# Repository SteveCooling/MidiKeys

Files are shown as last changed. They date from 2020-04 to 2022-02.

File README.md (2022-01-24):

# MidiKeys

Dissecting an old broken organ I got the idea to turn it into a MIDI keyboard.

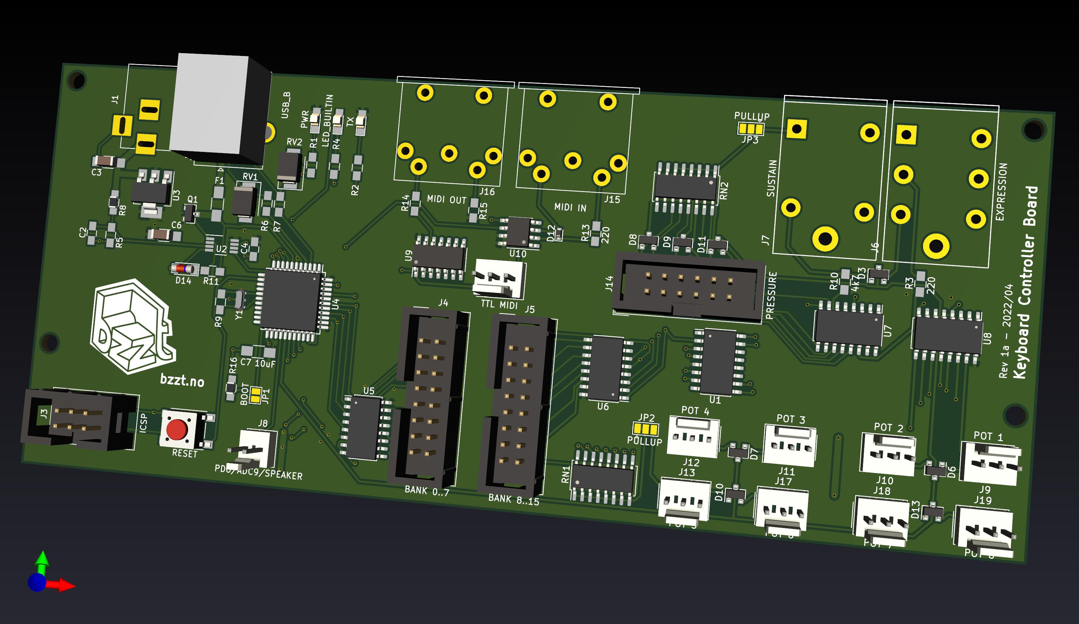
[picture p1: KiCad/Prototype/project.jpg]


I've since gotten a keybed that already had dual key switches for the velocity sensitivity, and been working on circuitry and code to support velocity sensitivity.

My plan is to produce a versatile open source keyboard controller board that can be used in various keyboard projects.

Works:

* Velocity sensitive multiplexed keyboard scanning
* Note off velocity sensitivity (not common in commercial keyboards, fun to be had here)

Plans:

* Work out the bugs in the keyboard scanner (keys sometimes hang or go undetected)
* Pot/slider (analog input) multiplexing
* Dedicated PCB with all required components and connectors
* Aftertouch support (channel pressure)
  * Maybe pseudo-polyphonic aftertouch is possible using a handful of pressure sensors (one per octave?) and interpolating the key pressure. Not sure about this.

Maybe in time:

* Mackie style DAW control support
* Keyboard splits and layers
* Interactive configuration from computer
* Arpeggiator with some cool touches?
  * Internal or MIDI timing
  * Oneshot/lick mode: Only arpeggiate when multiple keys are on, and in play order. Lay a chord and let the keyboard "slide" through the notes for you. In tempo.

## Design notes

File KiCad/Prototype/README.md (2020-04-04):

# Prototype keyboard controller

Based on Arduino Leonardo (ATMEGA32U4)

:warning: NOT FINISHED

Will be a complete board with decoders for multiplexed sampling of analog sources and up to 61-key keybeds

## Origins

This KiCad project is a derivative of the work found here: https://github.com/aspro648/Leonardo/

## Bill Of Materials

:warning: This list is from the original project, needs update when the board is ready
  
- 1 ea., Perfect Purple PCB from OSH Park, with not so perfect layout from kicad.pcb file.
- 1 ea., U1 IC REG LINEAR 3.3V 150MA SOT23-5, LP2985-33DBVRG4, https://www.digikey.com/short/j29pqr
- 1 ea., U2 IC OPAMP GP 1MHZ RRO 8VSSOP, LM358DGKR, https://www.digikey.com/short/jnd53r
- 1 ea., U3 IC REG LINEAR 5V 1A SOT223 NCP1117ST50T3G, https://www.digikey.com/short/j29pqc
- 1 ea., U4 ATMEGA32U4-AU, IC MCU 8BIT 32KB FLASH 44TQFP, https://www.digikey.com/short/jb25pc
- 1 ea., Q1 MOSFET P-CH 20V 2A SSOT3, FDN340P, https://www.digikey.com/short/j29ppj

- 1 ea., Y1 CER RES 16.0000MHZ 15PF SMD, CSTCE16M0V53-R0, https://www.digikey.com/short/j2b9cm
- 2 ea., C1, C5 CAP CER 1UF SMD 0805
- 1 ea., C2 CAP CER 22pF SMD 0805
- 2 ea., C3, C6, C7 CAP CER 10UF 25V 1206, https://www.digikey.com/short/j29pwm
- 1 ea., C4 CAP CER 0.1UF SMD 0805

- 4 ea., D1-D4 SMD LED 0805, https://www.digikey.com/short/jwj4rb
- 1 ea., F1 PTC 1206, Bel 0ZCJ0025AF2E, https://www.digikey.com/short/jfcbc8
- 2 ea., RV1, RV2 VARISTOR 	VARISTOR 10.8V 40A 0805, https://www.digikey.com/short/jwj45d
- 4 ea., R1-R4 Resistor 1K OHM SMD 0805, https://www.digikey.com/short/j2d0wt
- 2 ea., R5, R8 Resistor 10K OHM SMD 0805, https://www.digikey.com/short/j2d0w4
- 2 ea., R6, R7 Resistor 22 OHM SMD 0805, https://www.digikey.com/short/jwj45j
- 1 ea., R9 Resistor 1M OHM SMD 0603, 

- 1 ea., SW1 (yellow) SWITCH TACTILE SPST-NO 0.05A 12V, SW416-ND, https://www.digikey.com/short/jwj4m9
- or (purple) KSEM31J LFS https://www.digikey.com/short/jnqh3m
- 1 ea., X3, CONN RCPT MICRO USB R/A SMD, Molex 1050170001, https://www.digikey.com/short/jb2205
- 1 ea., J1 Barrel Jack, https://www.digikey.com/short/j2fz43
- 1 ea., 6-Pin header, https://www.digikey.com/short/jwj4w4
- 2 ea., 8-Pin header, https://www.digikey.com/short/jwj4dp
- 1 ea., 10-Pin header, https://www.digikey.com/short/jwj4n7
- 1 ea., 2x3 Pin header, http://www.digikey.com/short/3m33n0

## License

[Attribution-ShareAlike 3.0 United States (CC BY-SA 3.0 US)](https://creativecommons.org/licenses/by-sa/3.0/us/)

You are free to:

- Share — copy and redistribute the material in any medium or format
- Adapt — remix, transform, and build upon the material

Under the following terms:

- Attribution — You must give appropriate credit, provide a link to the license, and indicate if changes were made. You may do so in any reasonable manner, but not in any way that suggests the licensor endorses you or your use.
- ShareAlike — If you remix, transform, or build upon the material, you must distribute your contributions under the same license as the original.

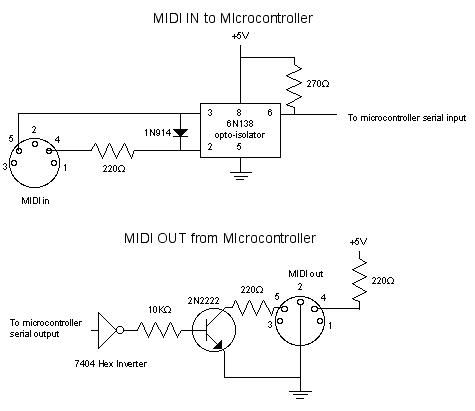
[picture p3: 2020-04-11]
KiCad/Prototype/documents/midi in out.jpg

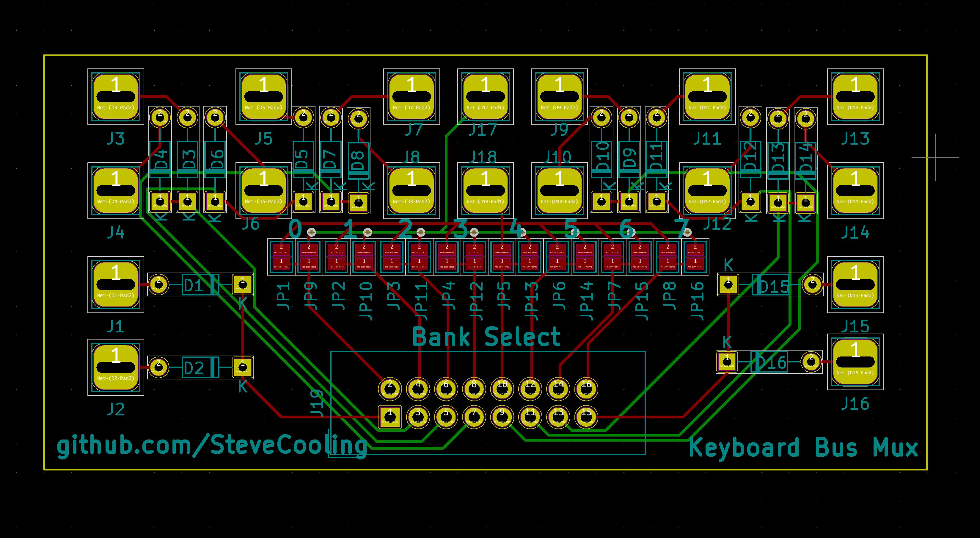
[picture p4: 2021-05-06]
KiCad/National Keyboard Mux Board/pcb0325.jpg

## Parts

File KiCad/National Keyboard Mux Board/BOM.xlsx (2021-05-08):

Comment | Designator | Footprint | LCSC Part #
Dual Common Cathode Diode | D8,D7,D6,D5,D4,D3,D2,D1 | SOT-23 | C82481

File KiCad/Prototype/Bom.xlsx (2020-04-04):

Description | Manufacturer Part Number | Manufacturer | Digi-Key Part Number | Customer Reference | Quantity | $ at Qty 1 | $ at Qty 25 | Total @ Qty 1 | Tota @ Qty 25
PCB |  | OSH Park | - | - | 1 | $9.48 | $5.72 | $9.48 | $5.72 | ~$2.60 JLCPCB?
IC REG LINEAR 3.3V 150MA SOT23-5 | LP2985-33DBVRG4 | Texas Instruments | 296-49790-1-ND | Leo U1 | 1 | $0.60 | $0.53 | $0.60 | $0.53
IC OPAMP GP 1MHZ RRO 8VSSOP | LMV358IDGKR | Texas Instruments | 296-13455-1-ND | Leo U2 | 1 | $0.80 | $0.71 | $0.80 | $0.71
IC MCU 8BIT 32KB FLASH 44TQFP | ATMEGA32U4-AUR | Microchip Technology | ATMEGA32U4-AURCT-ND | Leo U4 | 1 | $4.20 | $3.85 | $4.20 | $3.85
IC REG LINEAR 5V 1A SOT223 | NCP1117ST50T3G | ON Semiconductor | NCP1117ST50T3GOSCT-ND | Leo U3 | 1 | $0.54 | $0.46 | $0.54 | $0.46
MOSFET P-CH 20V 2A SSOT3 | FDN340P | ON Semiconductor | FDN340PCT-ND | Leo Q1 | 1 | $0.55 | $0.43 | $0.55 | $0.43
CER RES 16.0000MHZ 15PF SMD | CSTCE16M0V53-R0 | Murata Electronics North America | 490-1198-1-ND | Leo Y1 | 1 | $0.50 | $0.42 | $0.50 | $0.42
CAP CER 10UF 35V X5R 1206 | GRM319R6YA106KA12D | Murata Electronics North America | 490-9964-1-ND | Leo C3, C6, C7 | 3 | $0.41 | $0.16 | $1.23 | $0.48
CAP CER 0.1UF 25V X7R 0805 | CC0805KRX7R8BB104 | Yageo | 311-1141-1-ND | Leo C4 | 1 | $0.13 | $0.10 | $0.13 | $0.10
CAP CER 22PF 25V C0G/NP0 0805 | 885012007030 | Wurth Electronics Inc. | 732-7829-1-ND | Leo C2 | 1 | $0.10 | $0.05 | $0.10 | $0.05
CAP CER 1UF 25V X5R 0805 | CL21A105KAFNNNE | Samsung Electro-Mechanics | 1276-2887-1-ND | Leo C1, C5 | 2 | $0.19 | $0.14 | $0.38 | $0.28
PTC RESET FUSE 24V 250MA 1206 | 0ZCJ0025AF2E | Bel Fuse Inc. | 507-1799-1-ND | Leo F1 | 1 | $0.13 | $0.13 | $0.13 | $0.13
VARISTOR 10.8V 40A 0805 | VCUG080050L1DP | AVX Corporation | 478-5584-1-ND | Leo RV1, RV2 | 2 | $0.49 | $0.36 | $0.98 | $0.72
RES SMD 1K OHM 5% 1/8W 0805 | ERJ-6GEYJ102V | Panasonic Electronic Components | P1.0KACT-ND | Leo R1 - R4 | 4 | $0.10 | $0.03 | $0.40 | $0.12
RES SMD 10K OHM 5% 1/8W 0805 | ERJ-6GEYJ103V | Panasonic Electronic Components | P10KACT-ND | Leo R5, R8 | 2 | $0.10 | $0.03 | $0.20 | $0.06
RES SMD 22 OHM 5% 0.4W 0805 | ESR10EZPJ220 | Rohm Semiconductor | RHM22KCT-ND | Leo R6, R7 | 2 | $0.10 | $0.03 | $0.20 | $0.06
CRGCQ 0603 1M0 5% | CRGCQ0603J1M0 | TE Connectivity Passive Product | A130109CT-ND | Leo R9 | 1 | $0.10 | $0.03 | $0.10 | $0.03
LED ORANGE CLEAR SMD | LTST-C170KFKT | Lite-On Inc. | 160-1413-1-ND | Leo D1-D4 | 4 | $0.31 | $0.12 | $1.24 | $0.48
SWITCH TACTILE SPST-NO 0.05A 24V | B3S-1002 | Omron Electronics Inc-EMC Div | SW416-ND | Leo SW1 | 1 | $0.66 | $0.62 | $0.66 | $0.62
CONN RCPT MICRO USB R/A SMD | 1050170001 | Molex, LLC | WM1399CT-ND | Leo X3 | 1 | $0.87 | $0.72 | $0.87 | $0.72
CONN PWR JACK 2X5.5MM SOLDER | PJ-002A | CUI Inc. | CP-002A-ND | Leo J1 | 1 | $0.61 | $0.52 | $0.61 | $0.52
CONN HEADER FEMALE 6POS .1" TIN | PPTC061LFBN-RC | Sullins Connector Solutions | S7004-ND | Leo | 1 | $0.52 | $0.48 | $0.52 | $0.48
CONN HEADER FEMALE 8POS .1" TIN | PPTC081LFBN-RC | Sullins Connector Solutions | S7006-ND | Leo | 2 | $0.65 | $0.61 | $1.30 | $1.22
CONN HEADER FEMALE 10POS.1" TIN | PPTC101LFBN-RC | Sullins Connector Solutions | S7008-ND | Leo | 1 | $0.65 | $0.57 | $0.65 | $0.57
 |  |  |  |  |  |  |  | $26.37 | $18.76

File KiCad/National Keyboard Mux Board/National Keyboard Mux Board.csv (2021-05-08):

Id | Designator | Footprint | Quantity | Designation | LCSC
1 | D8,D7,D6,D5,D4,D3,D2,D1 | SOT-23 | 8 | BAV74LT1G | C82481

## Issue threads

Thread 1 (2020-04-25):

Key changes are sometimes not detected

SteveCooling, 2020-04-25:
Sometimes a note will hang (not turn off) or not get detected.

This might be caused by bounce in the switches combined with the fact that we send a XOR of the state out of the keyboard reader.

Try to:
* Stop using XOR to get a definitive state of each key.
* Internalize the velocity logic into KeyboardMux - direct access to the key states and easier to work with for the user.

SteveCooling, 2020-05-05:
It seems this issue was a race condition in MidiKeys::loop() where PORTB would change over time when it was assumed to be the same. Earlier timing optimizations obviously made this better.

I'm now making a copy of the data on PORTB and using it for the duration of the function call, and I think that solved the issue. Needs more testing though. 🎶

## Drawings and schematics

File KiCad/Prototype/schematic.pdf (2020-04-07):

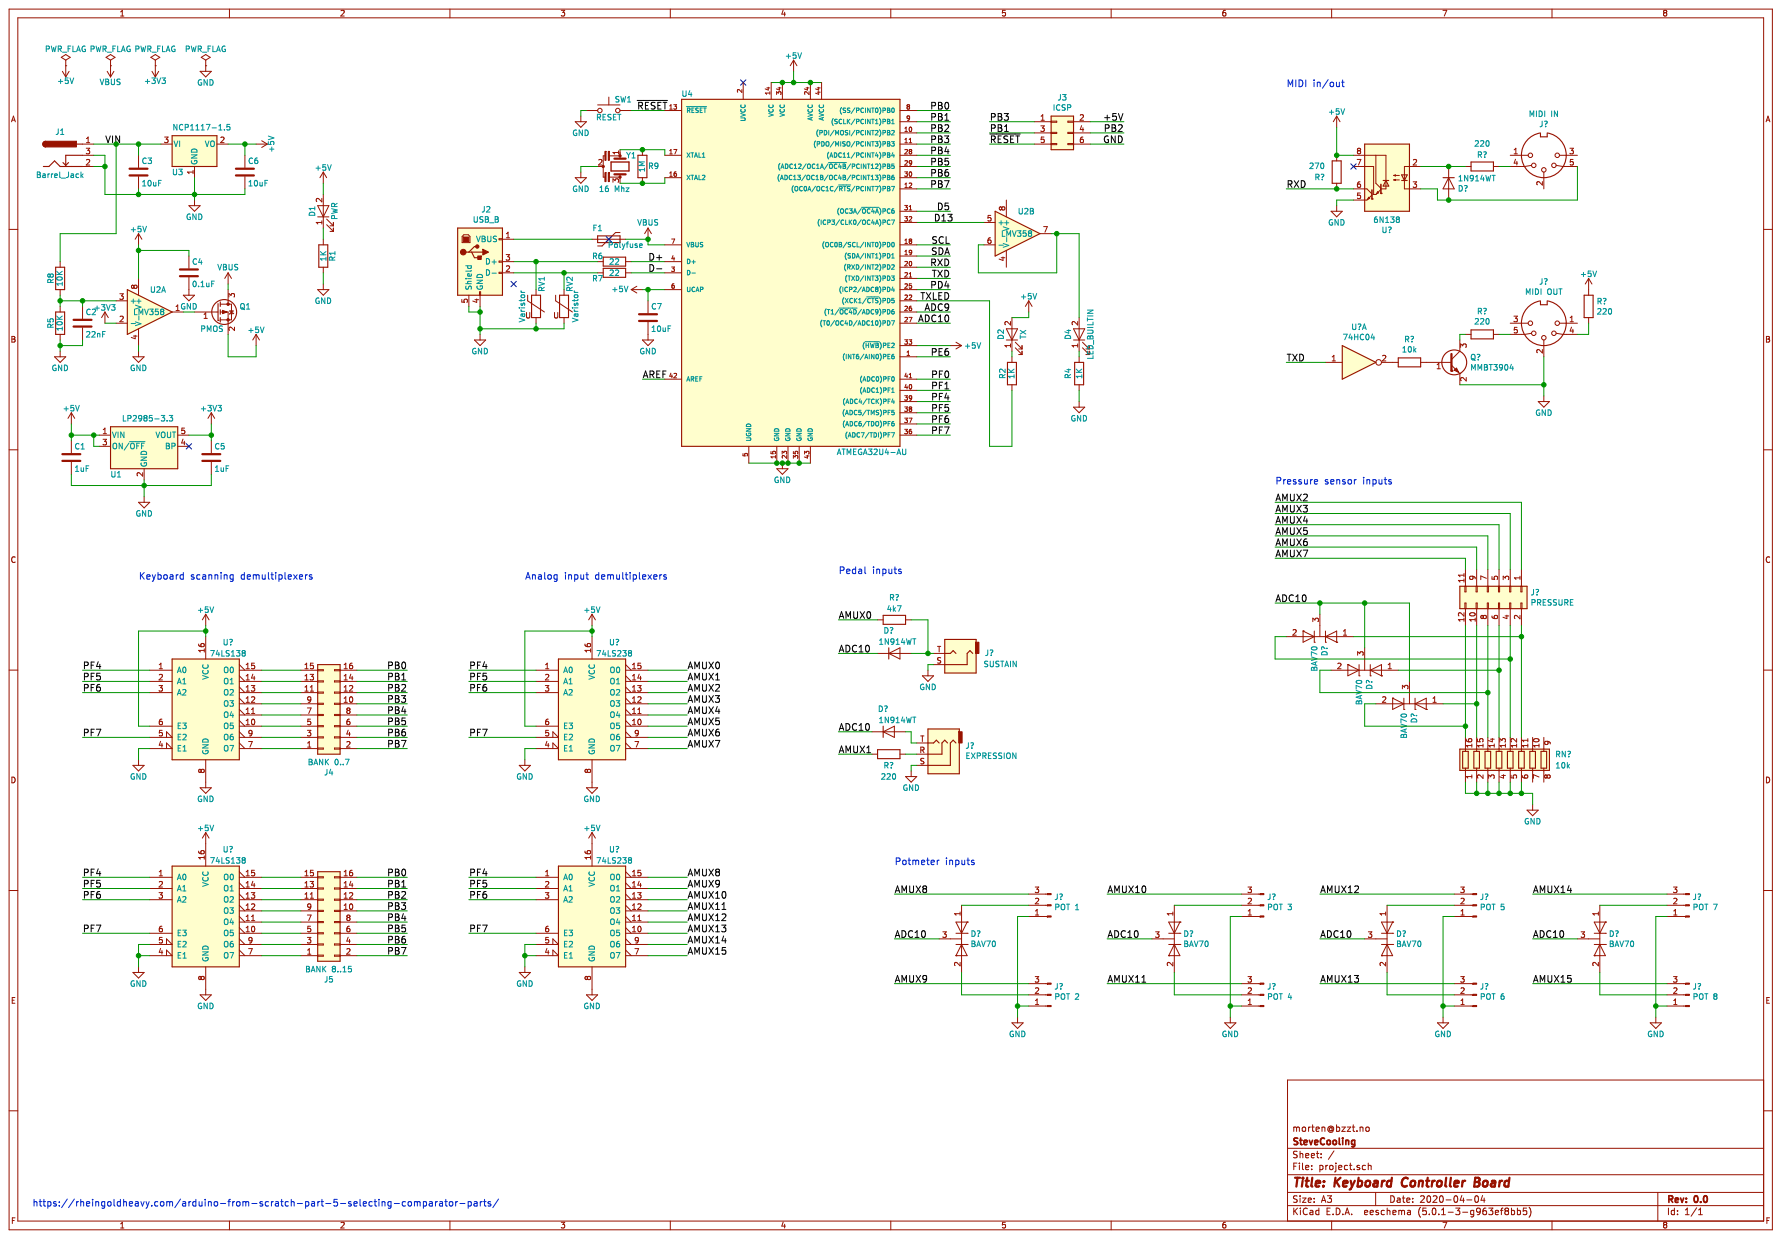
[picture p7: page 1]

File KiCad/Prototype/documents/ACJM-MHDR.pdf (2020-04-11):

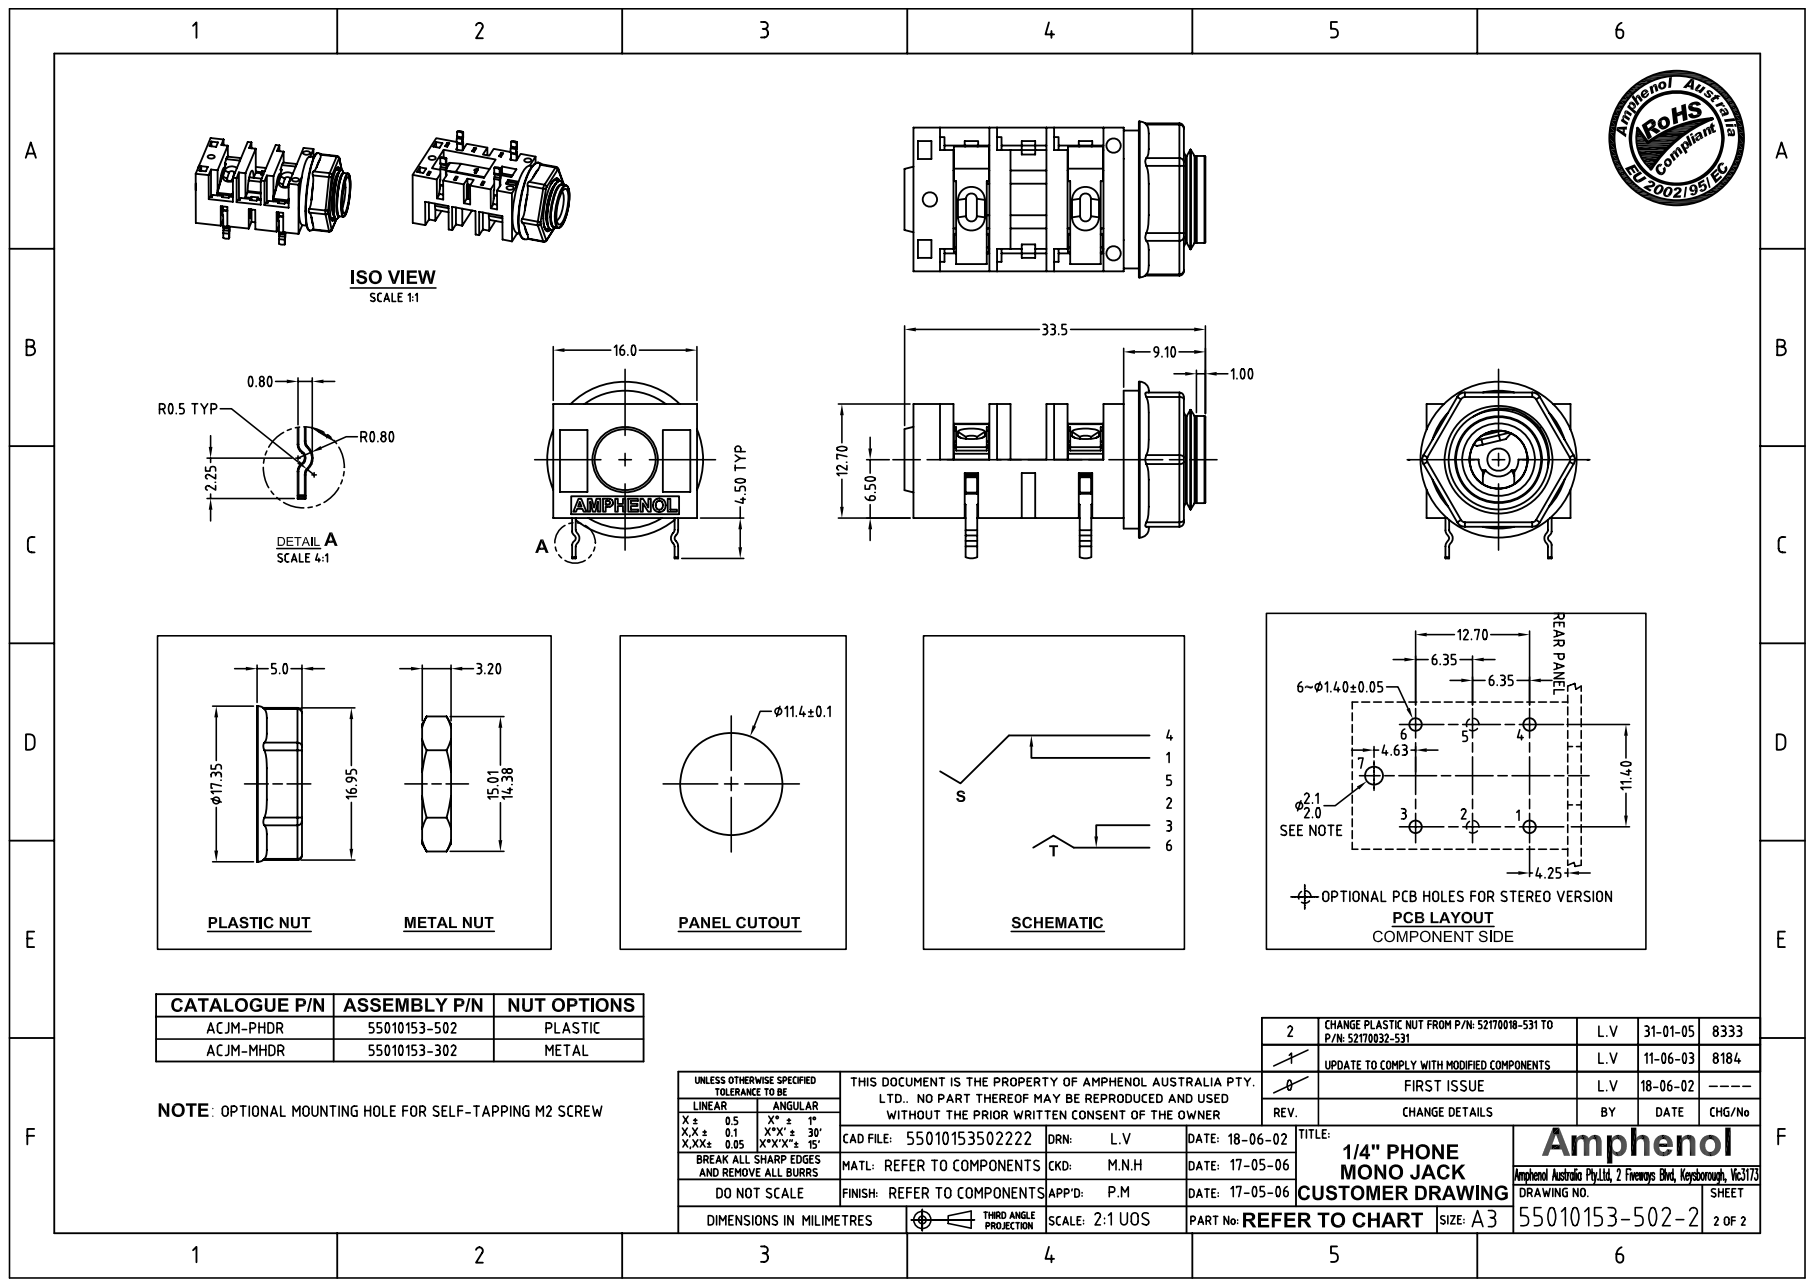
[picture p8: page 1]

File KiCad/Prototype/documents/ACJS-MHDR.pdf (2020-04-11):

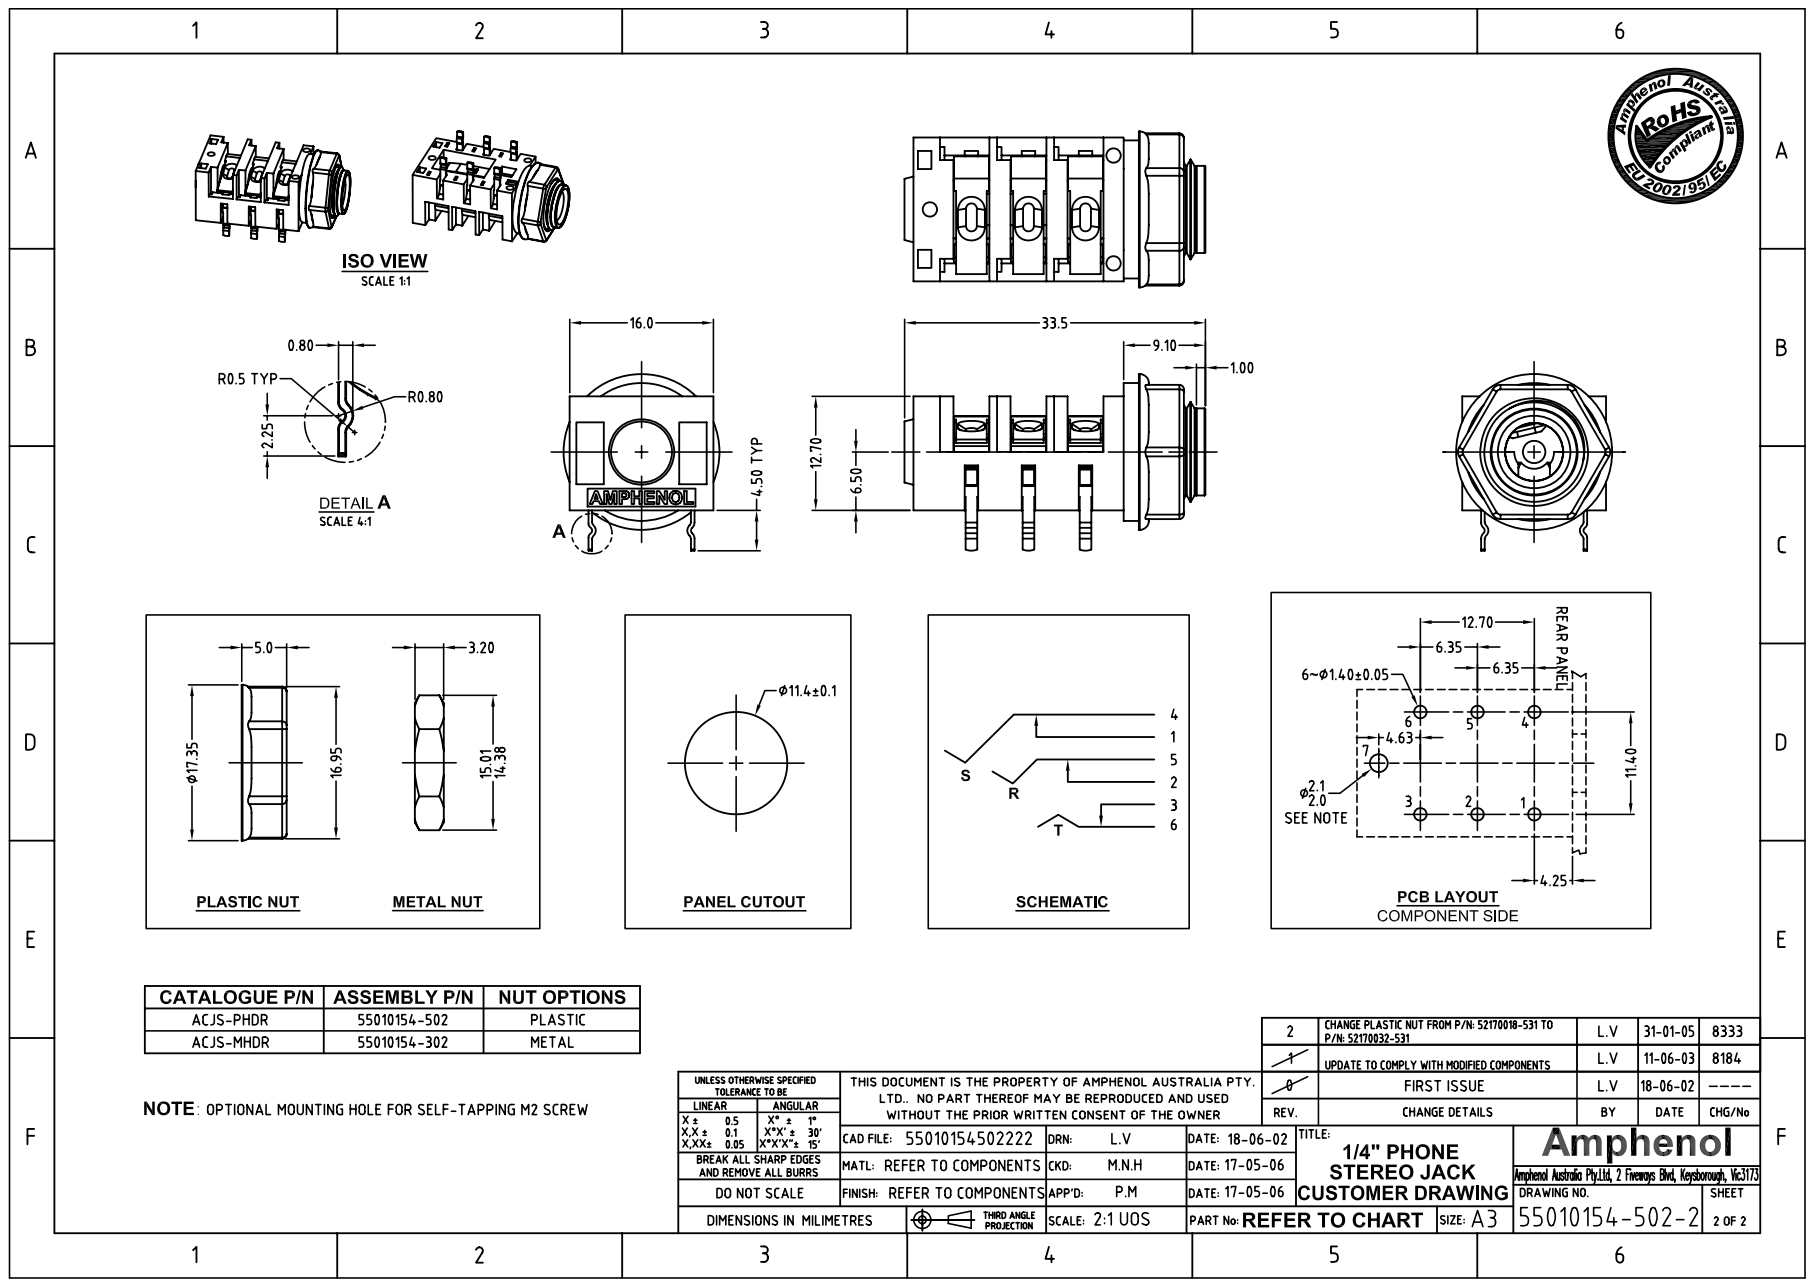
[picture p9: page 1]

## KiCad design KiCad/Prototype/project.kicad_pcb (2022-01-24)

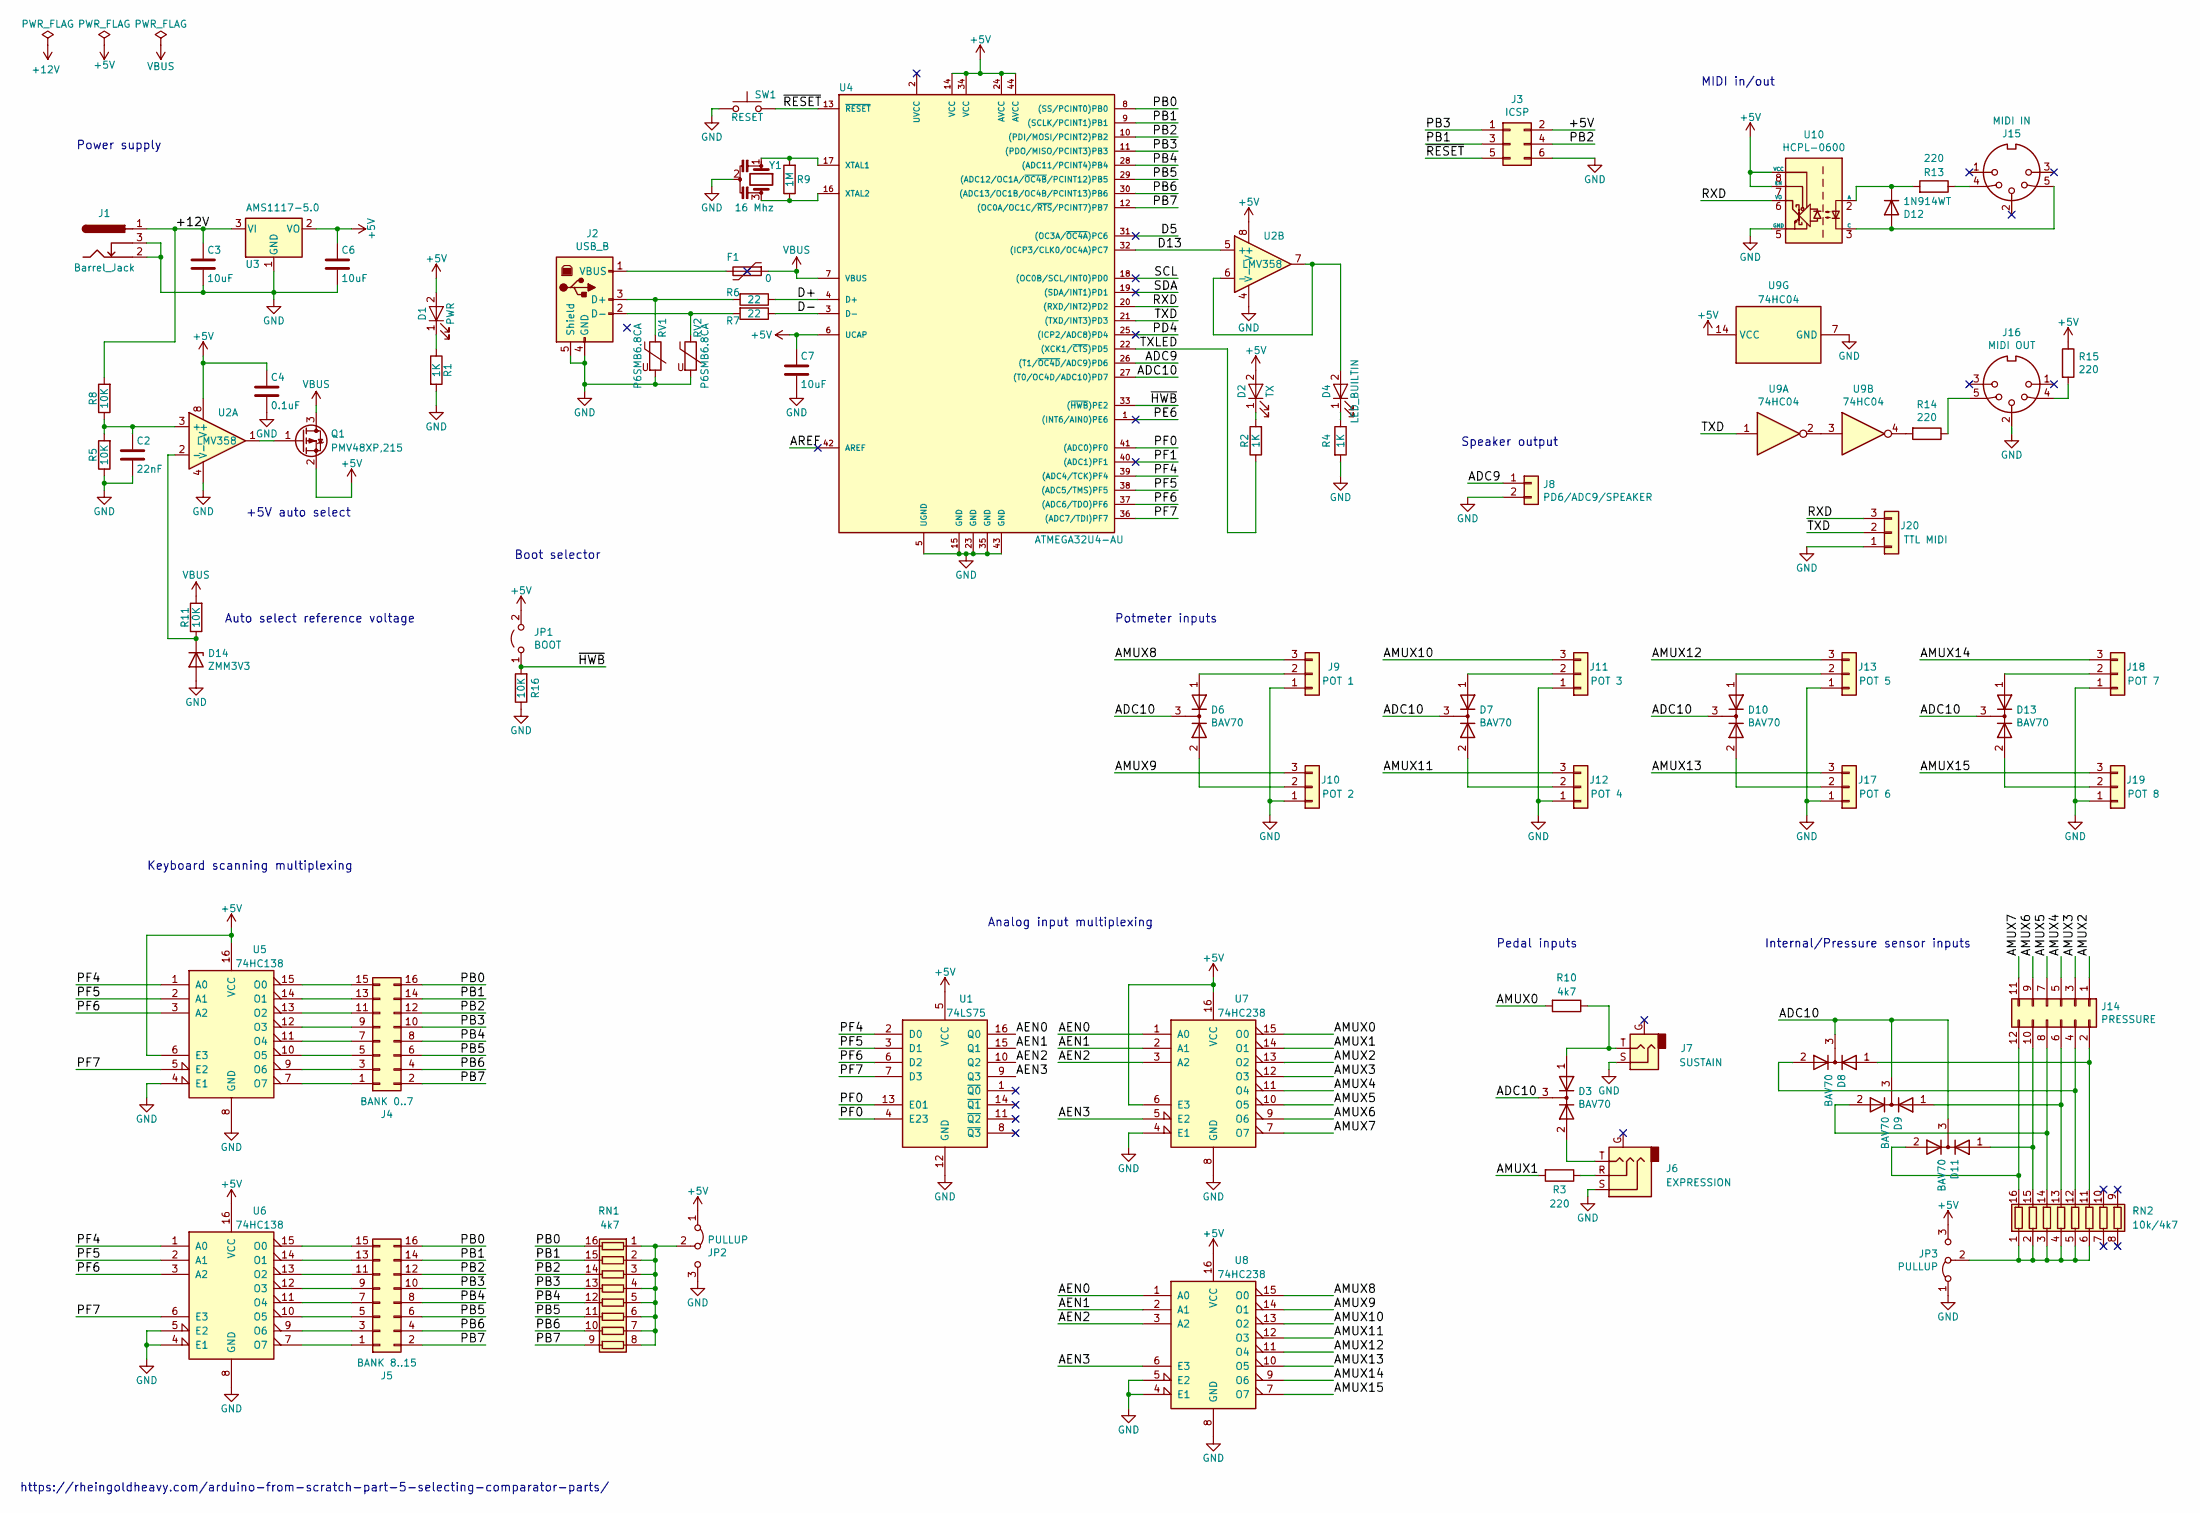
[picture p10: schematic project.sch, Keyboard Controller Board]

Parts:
C2: 22nF; C_0805_HandSoldering; LCSC C1729
C3, C6, C7: 10uF; C_1206_HandSoldering; LCSC C13585
C4: 0.1uF; C_0805_HandSoldering; LCSC C49678
D1: PWR; LED_0805_HandSoldering; LCSC C84256
D2: TX; LED_0805_HandSoldering; LCSC C84256
D3, D6, D7, D8, D9, D10, D11, D13: BAV70; SOT-23; LCSC C68978
D4: LED_BUILTIN; LED_0805_HandSoldering; LCSC C84256
D12: 1N914WT; D_SOD-323; LCSC C2128
D14: ZMM3V3; D_MiniMELF; LCSC C8056
F1: 0; R_1206_HandSoldering; LCSC C17888
J1: Barrel_Jack; BARREL_JACK; MOUSER 490-PJ-102A
J2: USB_B; USB_B_OST_USB-B1HSxx_Horizontal; MOUSER 490-UJ2-BH-1-TH
J3: ICSP; IDC-Header_2x03_P2.54mm_Vertical; MOUSER 517-30306-6002HB
J4: BANK 0..7; IDC-Header_2x08_P2.54mm_Vertical; MOUSER 517-30316-6002
J5: BANK 8..15; IDC-Header_2x08_P2.54mm_Vertical; MOUSER 517-30316-6002
J6: EXPRESSION; Jack_6.35mm_Amphenol_ACJS-MHDR; MOUSER 523-ACJS-MHOP
J7: SUSTAIN; Jack_6.35mm_Amphenol_ACJM-MHDR; MOUSER 523-ACJS-MHOP
J8: PD6/ADC9/SPEAKER; Molex_KK-254_AE-6410-02A_1x02_P2.54mm_Vertical; MOUSER 571-640454-2
J9: POT 1; Molex_KK-254_AE-6410-03A_1x03_P2.54mm_Vertical; MOUSER 571-6404543
J10: POT 2; Molex_KK-254_AE-6410-03A_1x03_P2.54mm_Vertical; MOUSER 571-6404543
J11: POT 3; Molex_KK-254_AE-6410-03A_1x03_P2.54mm_Vertical; MOUSER 571-6404543
J12: POT 4; Molex_KK-254_AE-6410-03A_1x03_P2.54mm_Vertical; MOUSER 571-6404543
J13: POT 5; Molex_KK-254_AE-6410-03A_1x03_P2.54mm_Vertical; MOUSER 571-6404543
J14: PRESSURE; IDC-Header_2x06_P2.54mm_Vertical
J15: MIDI IN; DIN_5_180Deg_PSG03463; MOUSER 806-KCDX-5S-N2
J16: MIDI OUT; DIN_5_180Deg_PSG03463; MOUSER 806-KCDX-5S-N2
J17: POT 6; Molex_KK-254_AE-6410-03A_1x03_P2.54mm_Vertical; MOUSER 571-6404543
J18: POT 7; Molex_KK-254_AE-6410-03A_1x03_P2.54mm_Vertical; MOUSER 571-6404543
J19: POT 8; Molex_KK-254_AE-6410-03A_1x03_P2.54mm_Vertical; MOUSER 571-6404543
J20: TTL MIDI; Molex_KK-254_AE-6410-03A_1x03_P2.54mm_Vertical; MOUSER 571-6404543
JP1: BOOT; SolderJumper-2_P1.3mm_Open_Pad1.0x1.5mm
JP2, JP3: PULLUP; SolderJumper-3_P1.3mm_Bridged12_Pad1.0x1.5mm
Q1: PMV48XP,215; SOT-23; LCSC C75560
R1, R2, R4: 1K; R_0805_HandSoldering; LCSC C17513
R3, R13, R14, R15: 220; C_0805_HandSoldering; LCSC C17557
R5, R8, R11, R16: 10K; R_0805_HandSoldering; LCSC C17414
R6, R7: 22; R_0805_HandSoldering; LCSC C17561
R9: 1M; R_0805_HandSoldering; LCSC C17514
R10: 4k7; C_0805_HandSoldering; LCSC C17673
RN1: 4k7; SOIC-16_4.55x10.3mm_P1.27mm
RN2: 10k/4k7; SOIC-16_4.55x10.3mm_P1.27mm
RV1, RV2: P6SMB6.8CA; D_SMB; LCSC C78395
SW1: RESET; SW_SPST_PTS645
U1: 74LS75; SOIC-16_4.55x10.3mm_P1.27mm
U2: LMV358; VSSOP-8_3.0x3.0mm_Pitch0.65mm
U3: AMS1117-5.0; SOT-223-3_TabPin2; LCSC C6187
U4: ATMEGA32U4-AU; TQFP-44_10x10mm_Pitch0.8mm; MOUSER 556-ATMEGA32U4-AU
U5, U6: 74HC138; SOIC-16_4.55x10.3mm_P1.27mm; MOUSER 771-74HC138D
U7, U8: 74HC238; SOIC-16_4.55x10.3mm_P1.27mm; MOUSER 771-74HC238D
U9: 74HC04; SOIC-14_3.9x8.7mm_P1.27mm
U10: HCPL-0600; SOIC-8_3.9x4.9mm_P1.27mm; MOUSER 512-HCPL0600
Y1: 16 Mhz; Resonator_SMD_CTSC_1.3mmx3.2mm

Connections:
+5V: C4.1, C6.1, C7.1, D1.2 (A), D2.2 (A), J3.2, JP1.2 (B), JP2.1 (A), JP3.3 (B), Q1.2 (S), R15.1, U1.5 (VCC), U2.8 (V+), U3.2 (VO), U4.6 (UCAP), U4.14 (VCC), U4.24 (AVCC), U4.34 (VCC), U4.44 (AVCC), U5.6 (E3), U5.16 (VCC), U6.16 (VCC), U7.6 (E3), U7.16 (VCC), U8.16 (VCC), U9.14 (VCC), U10.7 (EN), U10.8 (VCC)
+12V: C3.1, J1.1, R8.2, U3.3 (VI)
/ADC9: J8.1, U4.26 ((T1/~OC4D~/ADC9)PD6)
/ADC10: D3.3 (K), D6.3 (K), D7.3 (K), D8.3 (K), D9.3 (K), D10.3 (K), D11.3 (K), D13.3 (K), U4.27 ((T0/OC4D/ADC10)PD7)
/AEN0: U1.16 (Q0), U7.1 (A0), U8.1 (A0)
/AEN1: U1.15 (Q1), U7.2 (A1), U8.2 (A1)
/AEN2: U1.10 (Q2), U7.3 (A2), U8.3 (A2)
/AEN3: U1.9 (Q3), U7.5 (E2), U8.6 (E3)
/AMUX0: R10.2, U7.15 (O0)
/AMUX1: R3.2, U7.14 (O1)
/AMUX2: J14.1, U7.13 (O2)
/AMUX3: J14.3, U7.12 (O3)
/AMUX4: J14.5, U7.11 (O4)
/AMUX5: J14.7, U7.10 (O5)
/AMUX6: J14.9, U7.9 (O6)
/AMUX7: J14.11, U7.7 (O7)
/AMUX8: J9.3, U8.15 (O0)
/AMUX9: J10.3, U8.14 (O1)
/AMUX10: J11.3, U8.13 (O2)
/AMUX11: J12.3, U8.12 (O3)
/AMUX12: J13.3, U8.11 (O4)
/AMUX13: J17.3, U8.10 (O5)
/AMUX14: J18.3, U8.9 (O6)
/AMUX15: J19.3, U8.7 (O7)
/AREF: U4.42 (AREF)
/D5: U4.31 ((OC3A/~OC4A~)PC6)
/D13: U2.5 (+), U4.32 ((ICP3/CLK0/OC4A)PC7)
/D+: R6.1, U4.4 (D+)
/D-: R7.1, U4.3 (D-)
/PB0: J4.16, J5.16, RN1.16 (R1.2), U4.8 ((SS/PCINT0)PB0)
/PB1: J3.3, J4.14, J5.14, RN1.15 (R2.2), U4.9 ((SCLK/PCINT1)PB1)
/PB2: J3.4, J4.12, J5.12, RN1.14 (R3.2), U4.10 ((PDI/MOSI/PCINT2)PB2)
/PB3: J3.1, J4.10, J5.10, RN1.13 (R4.2), U4.11 ((PDO/MISO/PCINT3)PB3)
/PB4: J4.8, J5.8, RN1.12 (R5.2), U4.28 ((ADC11/PCINT4)PB4)
/PB5: J4.6, J5.6, RN1.11 (R6.2), U4.29 ((ADC12/OC1A/~OC4B~/PCINT12)PB5)
/PB6: J4.4, J5.4, RN1.10 (R7.2), U4.30 ((ADC13/OC1B/OC4B/PCINT13)PB6)
/PB7: J4.2, J5.2, RN1.9 (R8.2), U4.12 ((OC0A/OC1C/~RTS~/PCINT7)PB7)
/PD4: U4.25 ((ICP2/ADC8)PD4)
/PE6: U4.1 ((INT6/AIN0)PE6)
/PF0: U1.4 (E23), U1.13 (E01), U4.41 ((ADC0)PF0)
/PF1: U4.40 ((ADC1)PF1)
/PF4: U1.2 (D0), U4.39 ((ADC4/TCK)PF4), U5.1 (A0), U6.1 (A0)
/PF5: U1.3 (D1), U4.38 ((ADC5/TMS)PF5), U5.2 (A1), U6.2 (A1)
/PF6: U1.6 (D2), U4.37 ((ADC6/TDO)PF6), U5.3 (A2), U6.3 (A2)
/PF7: U1.7 (D3), U4.36 ((ADC7/TDI)PF7), U5.5 (E2), U6.6 (E3)
/RXD: J20.3, U4.20 ((RXD/INT2)PD2), U10.6 (VO)
/SCL: U4.18 ((OC0B/SCL/INT0)PD0)
/SDA: U4.19 ((SDA/INT1)PD1)
/TXD: J20.2, U4.21 ((TXD/INT3)PD3), U9.1
/TXLED: R2.1, U4.22 ((XCK1/~CTS~)PD5)
/~HWB: JP1.1 (A), R16.2, U4.33 ((~HWB~)PE2)
/~RESET: J3.5, SW1.2, U4.13 (~RESET~)
GND: C2.2, C3.2, C4.2, C6.2, C7.2, D14.2 (A), J1.2, J1.3, J2.4 (GND), J2.5 (Shield), J3.6, J6.S, J7.S, J8.2, J9.1, J10.1, J11.1, J12.1, J13.1, J16.2, J17.1, J18.1, J19.1, J20.1, JP2.3 (B), JP3.1 (A), R1.2, R4.2, R5.1, R16.1, RV1.2, RV2.2, SW1.1, U1.12 (GND), U2.4 (V-), U3.1 (GND), U4.5 (UGND), U4.15 (GND), U4.23 (GND), U4.35 (GND), U4.43 (GND), U5.4 (E1), U5.8 (GND), U6.4 (E1), U6.5 (E2), U6.8 (GND), U7.4 (E1), U7.8 (GND), U8.4 (E1), U8.5 (E2), U8.8 (GND), U9.7 (GND), U10.5 (GND), Y1.2
unnamed: C2.1, R5.2, R8.1, U2.3 (+)
unnamed: D1.1 (K), R1.1
unnamed: D2.1 (K), R2.2
unnamed: D3.1 (A), J7.T, R10.1
unnamed: D3.2 (A), J6.T
unnamed: D4.1 (K), R4.1
unnamed: D4.2 (A), U2.6 (-), U2.7
unnamed: D6.1 (A), J9.2
unnamed: D6.2 (A), J10.2
unnamed: D7.1 (A), J11.2
unnamed: D7.2 (A), J12.2
unnamed: D8.1 (A), J14.2, RN2.11 (R6.2)
unnamed: D8.2 (A), J14.4, RN2.12 (R5.2)
unnamed: D9.1 (A), J14.6, RN2.13 (R4.2)
unnamed: D9.2 (A), J14.8, RN2.14 (R3.2)
unnamed: D10.1 (A), J13.2
unnamed: D10.2 (A), J17.2
unnamed: D11.1 (A), J14.10, RN2.15 (R2.2)
unnamed: D11.2 (A), J14.12, RN2.16 (R1.2)
unnamed: D12.1 (K), R13.2, U10.2 (A)
unnamed: D12.2 (A), J15.5, U10.3 (C)
unnamed: D13.1 (A), J18.2
unnamed: D13.2 (A), J19.2
unnamed: D14.1 (K), R11.1, U2.2 (-)
unnamed: F1.2, J2.1 (VBUS)
unnamed: J2.2 (D-), R7.2, RV2.1
unnamed: J2.3 (D+), R6.2, RV1.1
unnamed: J4.1, U5.7 (O7)
unnamed: J4.3, U5.9 (O6)
unnamed: J4.5, U5.10 (O5)
unnamed: J4.7, U5.11 (O4)
unnamed: J4.9, U5.12 (O3)
unnamed: J4.11, U5.13 (O2)
unnamed: J4.13, U5.14 (O1)
unnamed: J4.15, U5.15 (O0)
unnamed: J5.1, U6.7 (O7)
unnamed: J5.3, U6.9 (O6)
unnamed: J5.5, U6.10 (O5)
unnamed: J5.7, U6.11 (O4)
unnamed: J5.9, U6.12 (O3)
unnamed: J5.11, U6.13 (O2)
unnamed: J5.13, U6.14 (O1)
unnamed: J5.15, U6.15 (O0)
unnamed: J6.R, R3.1
unnamed: J15.4, R13.1
unnamed: J16.4, R15.2
unnamed: J16.5, R14.1
unnamed: JP2.2 (C), RN1.1 (R1.1), RN1.2 (R2.1), RN1.3 (R3.1), RN1.4 (R4.1), RN1.5 (R5.1), RN1.6 (R6.1), RN1.7 (R7.1), RN1.8 (R8.1)
unnamed: JP3.2 (C), RN2.1 (R1.1), RN2.2 (R2.1), RN2.3 (R3.1), RN2.4 (R4.1), RN2.5 (R5.1), RN2.6 (R6.1)
unnamed: Q1.1 (G), U2.1
unnamed: R9.1, U4.16 (XTAL2), Y1.3
unnamed: R9.2, U4.17 (XTAL1), Y1.1
unnamed: R14.2, U9.4
unnamed: U9.2, U9.3
VBUS: F1.1, Q1.3 (D), R11.2, U4.7 (VBUS)

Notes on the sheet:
https://rheingoldheavy.com/arduino-from-scratch-part-5-selecting-comparator-parts/
Keyboard scanning multiplexing
Analog input multiplexing
Potmeter inputs
Pedal inputs
Internal/Pressure sensor inputs
MIDI in/out
Speaker output
Power supply
Boot selector
+5V auto select
Auto select reference voltage

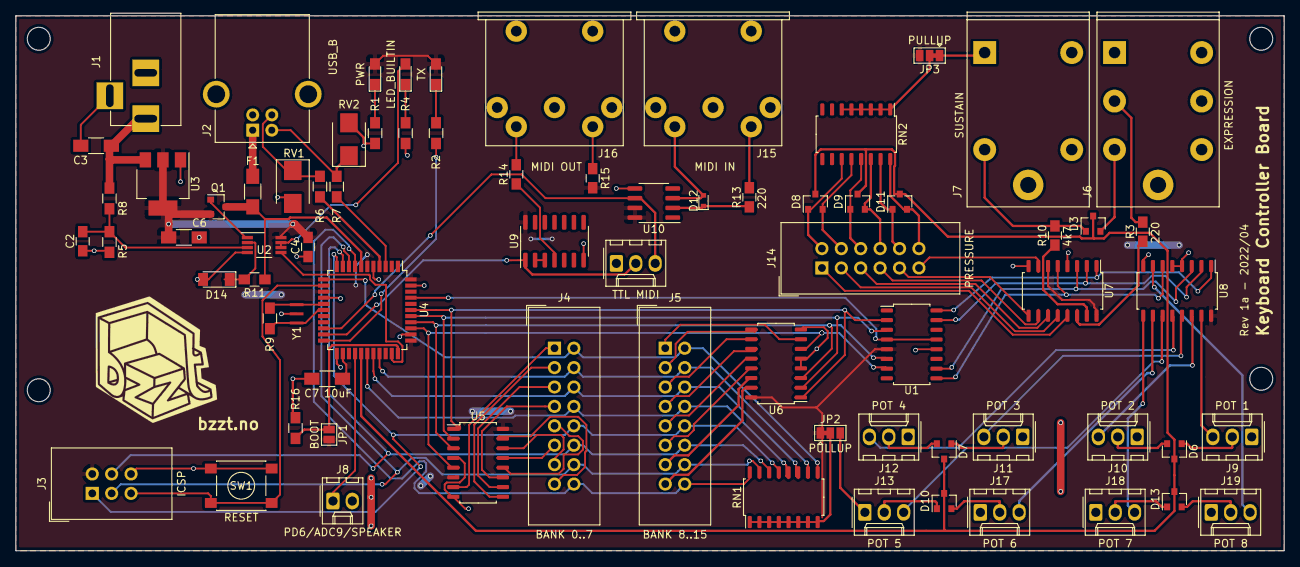
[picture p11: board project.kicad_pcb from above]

Board: 2 copper layers, 166.0 x 70.0 mm, 74 parts (0 on the bottom side), 101 nets.

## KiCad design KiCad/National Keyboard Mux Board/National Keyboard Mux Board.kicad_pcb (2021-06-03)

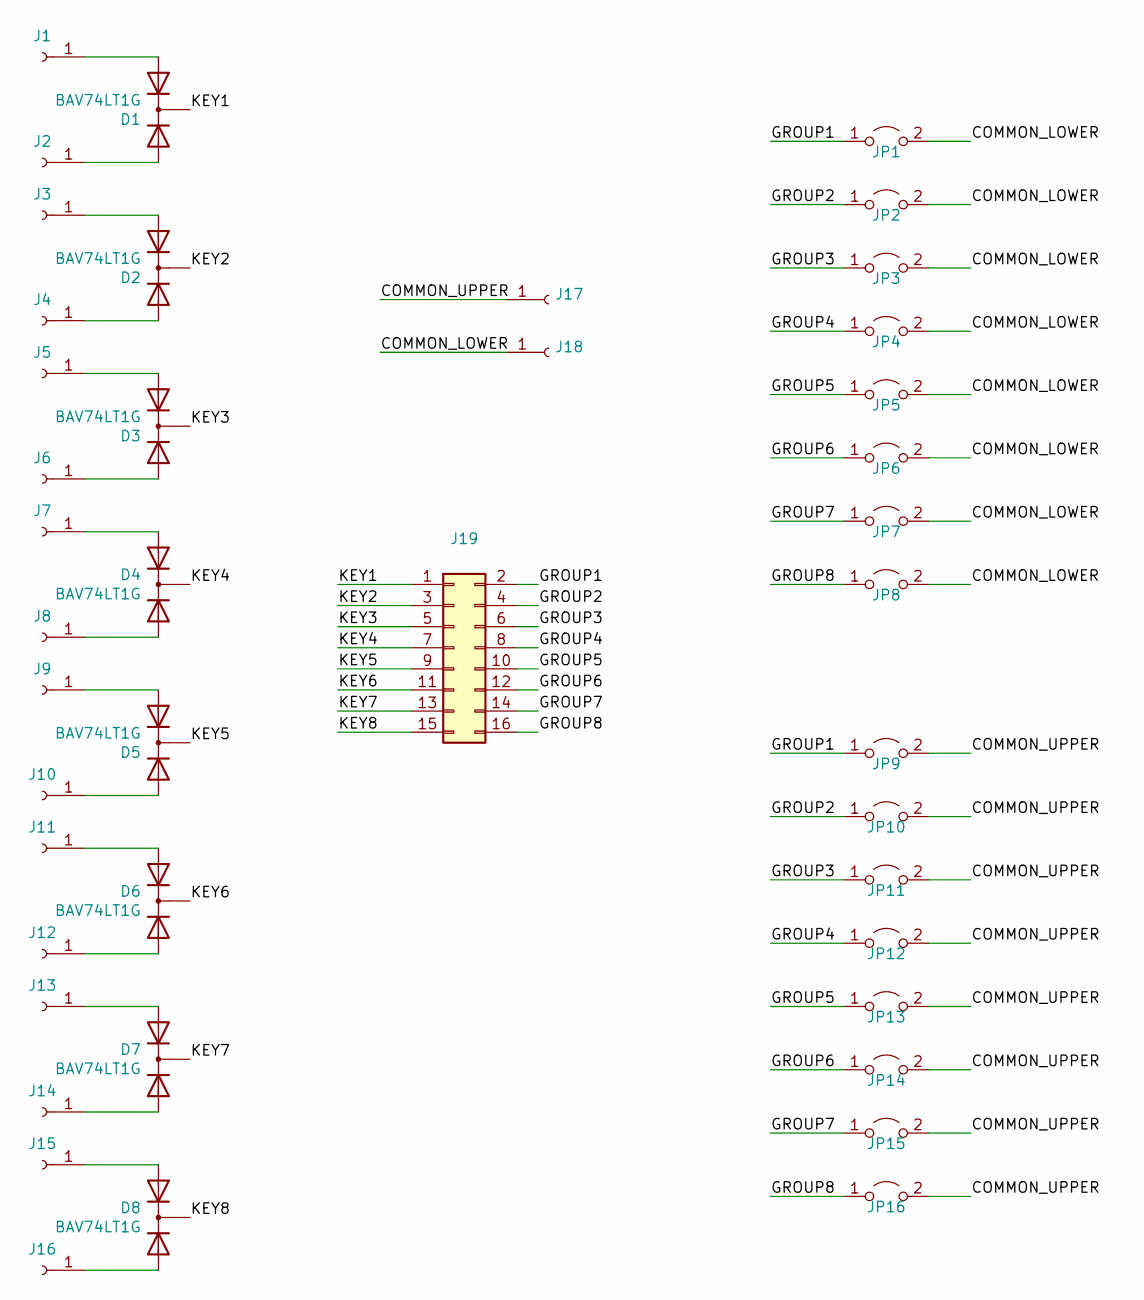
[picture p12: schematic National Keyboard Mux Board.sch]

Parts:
D1, D2, D3, D4, D5, D6, D7, D8: BAV74LT1G; SOT-23; LCSC C82481
J1, J2, J3, J4, J5, J6, J7, J8, J9, J10, J11, J12, J13, J14, J15, J16, J17, J18: Conn_01x01_Female; PinSlot_1x3.5mm_Flat
J19: Conn_02x08_Odd_Even; IDC-Header_2x08_P2.54mm_Vertical; LCSC C492443
JP1, JP2, JP3, JP4, JP5, JP6, JP7, JP8, JP9, JP10, JP11, JP12, JP13, JP14, JP15, JP16: Jumper_2_Open; SolderJumper-2_P1.3mm_Open_Pad1.0x1.5mm

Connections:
/COMMON_LOWER: J18.1, JP1.2 (B), JP2.2 (B), JP3.2 (B), JP4.2 (B), JP5.2 (B), JP6.2 (B), JP7.2 (B), JP8.2 (B)
/COMMON_UPPER: J17.1, JP9.2 (B), JP10.2 (B), JP11.2 (B), JP12.2 (B), JP13.2 (B), JP14.2 (B), JP15.2 (B), JP16.2 (B)
/GROUP1: J19.2, JP1.1 (A), JP9.1 (A)
/GROUP2: J19.4, JP2.1 (A), JP10.1 (A)
/GROUP3: J19.6, JP3.1 (A), JP11.1 (A)
/GROUP4: J19.8, JP4.1 (A), JP12.1 (A)
/GROUP5: J19.10, JP5.1 (A), JP13.1 (A)
/GROUP6: J19.12, JP6.1 (A), JP14.1 (A)
/GROUP7: J19.14, JP7.1 (A), JP15.1 (A)
/GROUP8: J19.16, JP8.1 (A), JP16.1 (A)
/KEY1: D1.3 (CATHODE), J19.1
/KEY2: D2.3 (CATHODE), J19.3
/KEY3: D3.3 (CATHODE), J19.5
/KEY4: D4.3 (CATHODE), J19.7
/KEY5: D5.3 (CATHODE), J19.9
/KEY6: D6.3 (CATHODE), J19.11
/KEY7: D7.3 (CATHODE), J19.13
/KEY8: D8.3 (CATHODE), J19.15
unnamed: D1.1 (ANODE_1), J1.1
unnamed: D1.2 (ANODE_2), J2.1
unnamed: D2.1 (ANODE_1), J3.1
unnamed: D2.2 (ANODE_2), J4.1
unnamed: D3.1 (ANODE_1), J5.1
unnamed: D3.2 (ANODE_2), J6.1
unnamed: D4.1 (ANODE_1), J8.1
unnamed: D4.2 (ANODE_2), J7.1
unnamed: D5.1 (ANODE_1), J9.1
unnamed: D5.2 (ANODE_2), J10.1
unnamed: D6.1 (ANODE_1), J12.1
unnamed: D6.2 (ANODE_2), J11.1
unnamed: D7.1 (ANODE_1), J14.1
unnamed: D7.2 (ANODE_2), J13.1
unnamed: D8.1 (ANODE_1), J16.1
unnamed: D8.2 (ANODE_2), J15.1

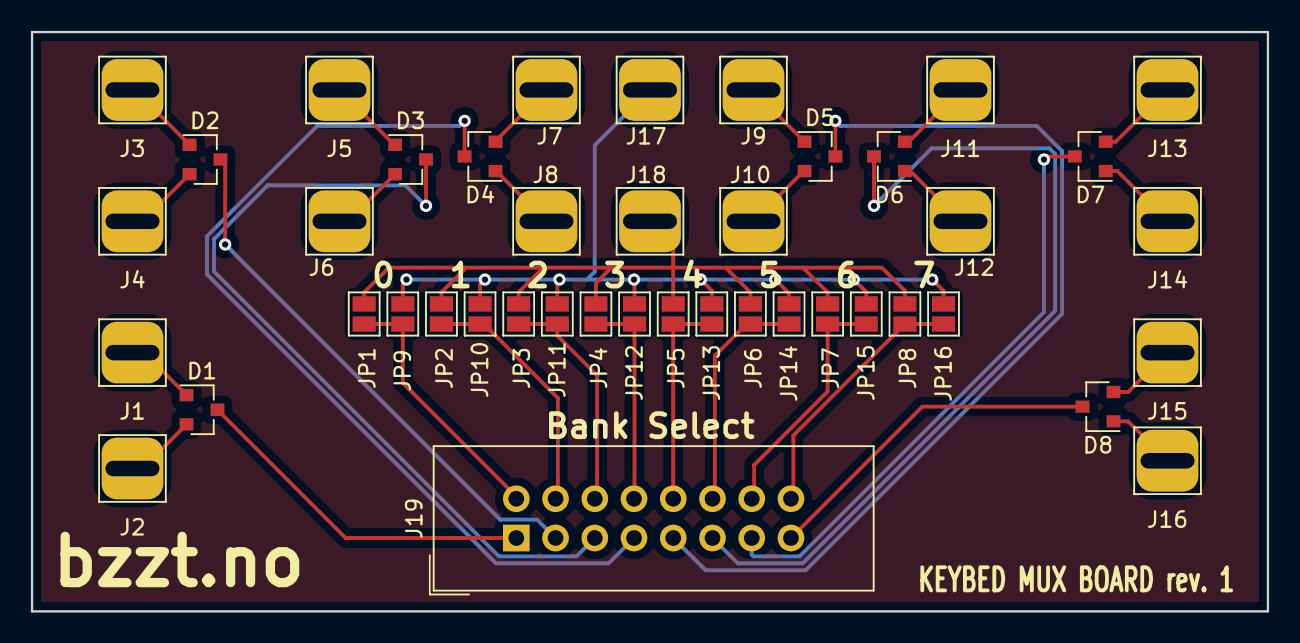
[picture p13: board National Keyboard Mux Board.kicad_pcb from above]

Board: 2 copper layers, 80.0 x 37.5 mm, 43 parts (0 on the bottom side), 34 nets.

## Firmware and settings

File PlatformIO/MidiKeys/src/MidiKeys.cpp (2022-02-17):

/**
 *
 * test.ino
 * 
 * Test use of the keyboard scanner library
 * Uses the MidiUSB extension to send MIDI over USB to the host
 * Reference: https://www.arduino.cc/en/Reference/MIDIUSB
 * 
 * Copyright (c) 2020 <morten@bzzt.no> 
 * 
 */

#define NUM_BANKS 16
#define NUM_NOTES 128
#define SIZE_NOTESTACK 64
#define SERIAL_DEBUG

// When this matches a primary key switch has been trigged
#define PRIMARY_BANK_MASK 0x01
#define PRIMARY_BANK_BITS 0x01

# define SPEAKER 12

//#include <math.h>
#include "KeyboardMux.h"
#include "Synth.h"

#include <MIDIUSB.h>
#include <EveryTimer.h>

#include "velocity.h"
#include "lut.h"

#define BLINKLED LED_BUILTIN
#define MIDI_CHAN 0

KeyboardMux keyboard;
Synth synth;
EveryTimer timer;

bool primary_bank;

// Timestamps for half events
unsigned long half_on[NUM_NOTES];
unsigned long half_off[NUM_NOTES];
// Stores computed velocity for each note
unsigned char note_velocity[NUM_NOTES];

char transpose = 24;

unsigned char playing = 0;
unsigned char notestack[SIZE_NOTESTACK];

float velocity_factor = 0.2;
float velocity_curve  = 60;

unsigned long time = micros();

unsigned char bankAndPosToNote(int bank, unsigned char pos) {
  // XXX: This requires primary/second bank bit to be LSB
  unsigned char note = (bank>>1) * 8;
  return note + (7-pos) + transpose;
}

unsigned char microsToVelocity(unsigned long micros) {
    if(micros >= 65535) micros = 65535;
    // Drop the 8 lowest bits of the microsecond duration and lookup the corresponding MIDI velocity
    unsigned char time = micros>>8;
    return velocity_log[time];
}

void noteOn(byte channel, byte pitch, byte velocity) {
  midiEventPacket_t noteOn = {0x09, 0x90 | channel, pitch, velocity};
  MidiUSB.sendMIDI(noteOn);
}

void noteOff(byte channel, byte pitch, byte velocity) {
  midiEventPacket_t noteOn = {0x08, 0x80 | channel, pitch, velocity};
  MidiUSB.sendMIDI(noteOn);
}

void noteChanged(unsigned char note, bool primary_bank) {


  /*
  if(note_velocity[note] == 0) {
    // Note is turning on
    if(primary_bank) {
      //Serial.println(" is half on");
      half_on[note] = time;
    } else {
      note_velocity[note] = microsToVelocity(time-half_on[note]);
      //half_on[note] = 0;
      noteOn(MIDI_CHAN, note, note_velocity[note]);
      #ifdef SERIAL_DEBUG
      Serial.print(note, DEC);
      Serial.print(" is fully on  - ");
      Serial.println(time-half_on[note], DEC);
      Serial.print(" - ");
      Serial.println(note_velocity[note], DEC);
      #endif
    }
  } else {
    // Note is turning off
    if(primary_bank) {
      note_velocity[note] = microsToVelocity(time-half_off[note]);
      //half_off[note] = 0;
      noteOff(MIDI_CHAN, note, note_velocity[note]);
      #ifdef SERIAL_DEBUG
      Serial.print(note, DEC);
      Serial.print(" is fully off - ");
      Serial.println(time-half_on[note], DEC);
      Serial.print(" - ");
      Serial.println(note_velocity[note], DEC);
      #endif
      note_velocity[note] = 0;
    } else {
      //Serial.println(" is half off");
      half_off[note] = time;
    }
  }*/

}

void noteOn(unsigned char note) {
  Serial.print("on\t");
  Serial.println(note, DEC);

  // Put the note in the stack
  playing += 1;
  notestack[playing] = note;

  synth.noteOn(note, time/1000);

}

void noteOff(unsigned char note) {
  Serial.print("off\t");
  Serial.println(note, DEC);

  for(unsigned char i = playing; i > 0; i --) {
    // Remove note from stack
    if(notestack[i] == note) {
      notestack[i] = 0;
      break;
    }
  }

  for(unsigned char i = playing; i > 0; i --) {
    if(notestack[i] != 0) {
      playing = i;
      synth.noteOn(notestack[i], time/1000);
      return;
    }
  }

  playing = 0;
  synth.noteOff();

}

void cb() {
  synth.update();
}

// the setup function runs once when you press reset or power the board
void setup() {
  // init arrays
  int c = 0;
  for(c=0; c < NUM_NOTES; c++) {
    half_on[c] = 0;
    half_off[c] = 0;
    note_velocity[c] = 0;
  }

  notestack[0] = 0;

  // initialize digital pin LED_BUILTIN as an output.
  pinMode(BLINKLED, OUTPUT);
  #ifdef SERIAL_DEBUG
  Serial.begin(115200);
  #endif
  // initialize the keyboard mux reader
  keyboard.init(true);

  keyboard.setNoteOn(noteOn);
  keyboard.setNoteOff(noteOff);

  timer.Every(10, cb);

  // Ready beep
  synth.init(SPEAKER);
}

// the loop function runs over and over again forever
void loop() {
  time = micros();
  keyboard.loop();
  MidiUSB.flush();
  timer.Update();
}

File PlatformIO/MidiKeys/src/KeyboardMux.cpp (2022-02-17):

/**
 *  KeyboardMux
 *  - Keyboard scanner for Arduino Leonardo (ATMEGA32U4)
 *
 *  Scan 16 banks (High nybble of PORTF) and read PORTB for each bank.
 * 
 *  For velocity sensitive keyboards, PORTF bit 4 selects the second switch for each key.
 *  Put another way: Bank 1 will be the secondary switches of bank 0.
 * 
 *  Output of LSB on PORTF is sent to the MUX and is subsequently read on PORTB.
 *  If you are running pullups on PORTB, set it low - if you need to read high bits, set it high.
 */

#include "KeyboardMux.h"
#include <avr/io.h>
#include <pins_arduino.h>

void KeyboardMux::init(bool pullup) {
  this->portb_invert = pullup;
  this->setupPortB();
  this->setupPortF();
}

void KeyboardMux::setupPortB() {
  // Disable RXLED, it is part of PORTB and is used to read the keyboard state
  RXLED0;
  // See ATMEGA 32u4 datasheet section 10.2.1
  // Pin directions (input)
  DDRB = 0x00;
  // Pull-ups enabled (board has physical pullups)
  PORTB = 0xFF; // 0xFF for enable pullups
}

void KeyboardMux::setupPortF() {
  // See ATMEGA 32u4 datasheet section 10.2.1
  // Pin directions (output)
  DDRF = 0xFF;
  // Default data
  PORTF = 0x00;
}

void KeyboardMux::setNoteOn(void (*noteOn)(unsigned char note)) {
  this->noteOn = noteOn;
}

void KeyboardMux::setNoteOff(void (*noteOff)(unsigned char note)) {
  this->noteOff = noteOff;
}

void KeyboardMux::bankChanged() {
  unsigned char pos;
  unsigned char note;

  unsigned char datanow  = this->state;
  unsigned char datalast = this->bankstate[this->current_bank];

  for(pos = 0; pos < 8; pos++) {
    // Compare last bit of datanow to datalast
    if((datanow & 0x01) ^ (datalast & 0x01)) {
      // This bit has flipped
      // Calculate note number. TODO: make this configurable
      note = this->current_bank - (pos * 6) - 173;

      // Callbacks
      if((datanow & 0x01) == 0x01) {
        this->portb_invert ? noteOff(note) : noteOn(note);
      } else {
        this->portb_invert ? noteOn(note) : noteOff(note);
      }
    }
    // Move on to the next bit in bank
    datanow = datanow>>1;
    datalast = datalast>>1;
  }
}

void KeyboardMux::loop() {

  // Read current bank state
  this->state = PINB;

  if(this->bankstate[this->current_bank] != this->state) {
    // State has changed
    this->bankChanged();
    // Save current bank state
    this->bankstate[this->current_bank] = this->state;
  }

  // Increment bank counter
  this->current_bank ++;
  this->current_bank = 0x0f & this->current_bank;

  // Do bank selection
  PORTF = (this->current_bank<<4) | PORTF_BASE;

}

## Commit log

2020-04-04 Work on velocity sensitivity
2020-04-04 started on PCB
2020-04-04 KiCad schematics
    [Bom.xlsx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]
2020-04-05 deleted an oops
    [Bom.xlsx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]
2020-04-05 mainly finished schematic
    [project.sch]
2020-04-05 more footprints
    [project.sch]
2020-04-07 more work on schematic, started layout
    [project.kicad_pcb]
2020-04-11 more routing
    [project.kicad_pcb, project.sch]
2021-05-06 committing older misc changes
    [project.sch]
2021-05-06 Include keybed mux bus PCB
    [National Keyboard Mux Board.kicad_pcb, National Keyboard Mux Board.sch]
2021-05-06 Swithed to dual SMT diodes and made schematic prettier
    [National Keyboard Mux Board.kicad_pcb]
2021-05-08 production files
    [BOM.xlsx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]
2021-05-10 Removed unneccessary 3V3 regulator Added latch for ADC multiplexing
    [project.sch]
2021-05-11 Readying schematic and routing for prototype production
    [project.kicad_pcb, project.sch]
2021-06-03 more work towards production
    [National Keyboard Mux Board.kicad_pcb, project.kicad_pcb, project.sch]
2021-10-19 minor tweaks
    [project.kicad_pcb, project.sch]
2022-01-17 missing connection. silkscreen adjustments.
    [project.kicad_pcb]
2022-01-24 Fix Kibot problems
    [project.kicad_pcb, project.sch]
2022-01-24 trying again
    [project.sch]
2022-01-24 Silkscreen Logo added
    [project.kicad_pcb]
2022-01-24 PCB photo
2022-02-17 bootloader and fuse settings
2022-02-17 bringup of new board.
